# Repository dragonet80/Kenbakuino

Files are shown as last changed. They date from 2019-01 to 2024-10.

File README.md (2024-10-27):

# Kenbakuino
This is a fork from: https://github.com/funnypolynomial/Kenbakuino

This is in WIP state!

Arduino emulation of the KENBAK-1




This is an Arduino-based emulation of the 
[KENBAK-1](https://en.wikipedia.org/wiki/Kenbak-1 "Wikipedia"), considered by some to be the first "personal computer".  It was first advertised for sale in the September 1971 issue of Scientific American.

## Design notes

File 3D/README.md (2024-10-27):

DWG (AutoCAD) and STL files



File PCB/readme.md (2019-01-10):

Fitxers per a la PCB en format Autodesk Eagle

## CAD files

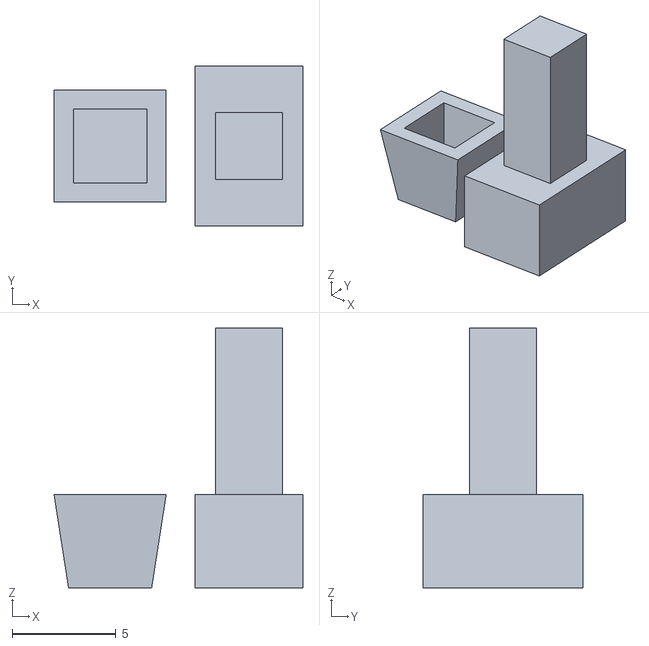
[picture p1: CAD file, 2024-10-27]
3D/Kenbak_boto3.stl
12.0 x 7.70 x 12.5

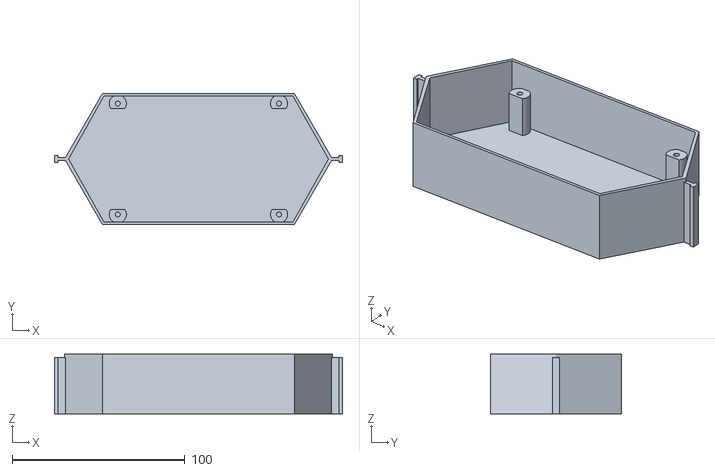
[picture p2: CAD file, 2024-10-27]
3D/Kenbak_caixa.stl
166.7 x 76.0 x 34.5

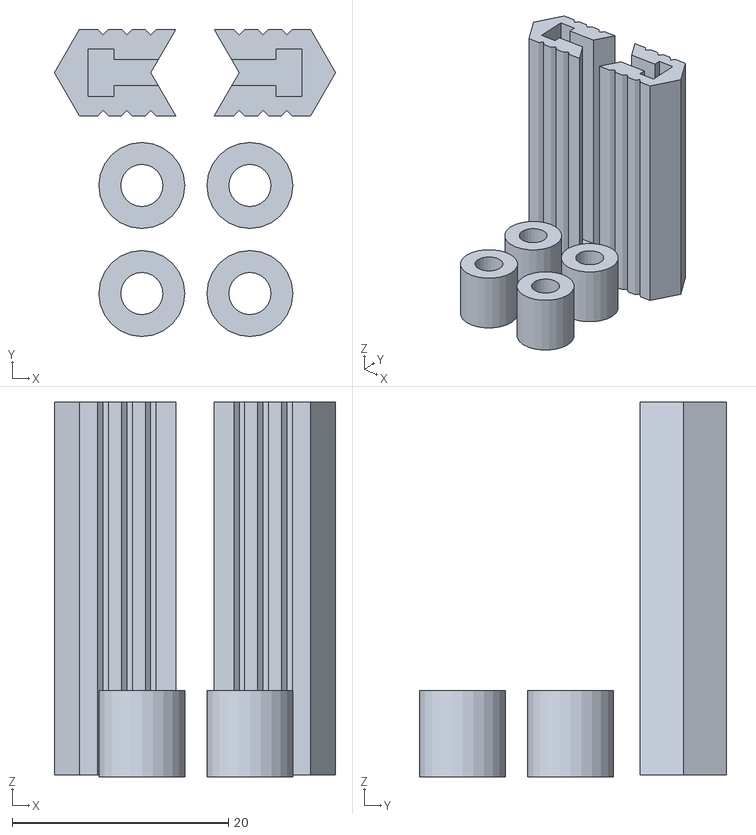
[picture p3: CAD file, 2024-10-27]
3D/Kenbak_tap.stl
26.0 x 28.4 x 34.7

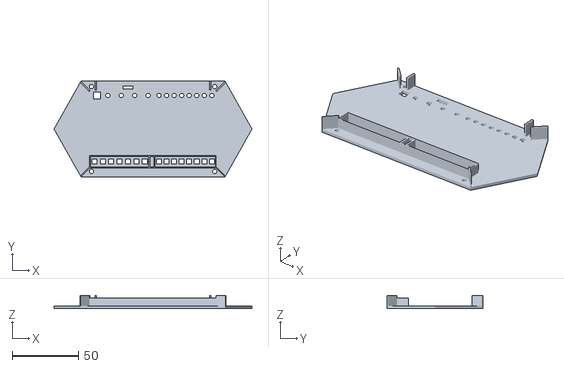
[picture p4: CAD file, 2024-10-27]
3D/Kenbak_tapa2.stl
149.9 x 72.6 x 10.00

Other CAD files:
3D/Kenbak-nanoduino_v2_005.dwg
3D/CajaKenbak3.dwg

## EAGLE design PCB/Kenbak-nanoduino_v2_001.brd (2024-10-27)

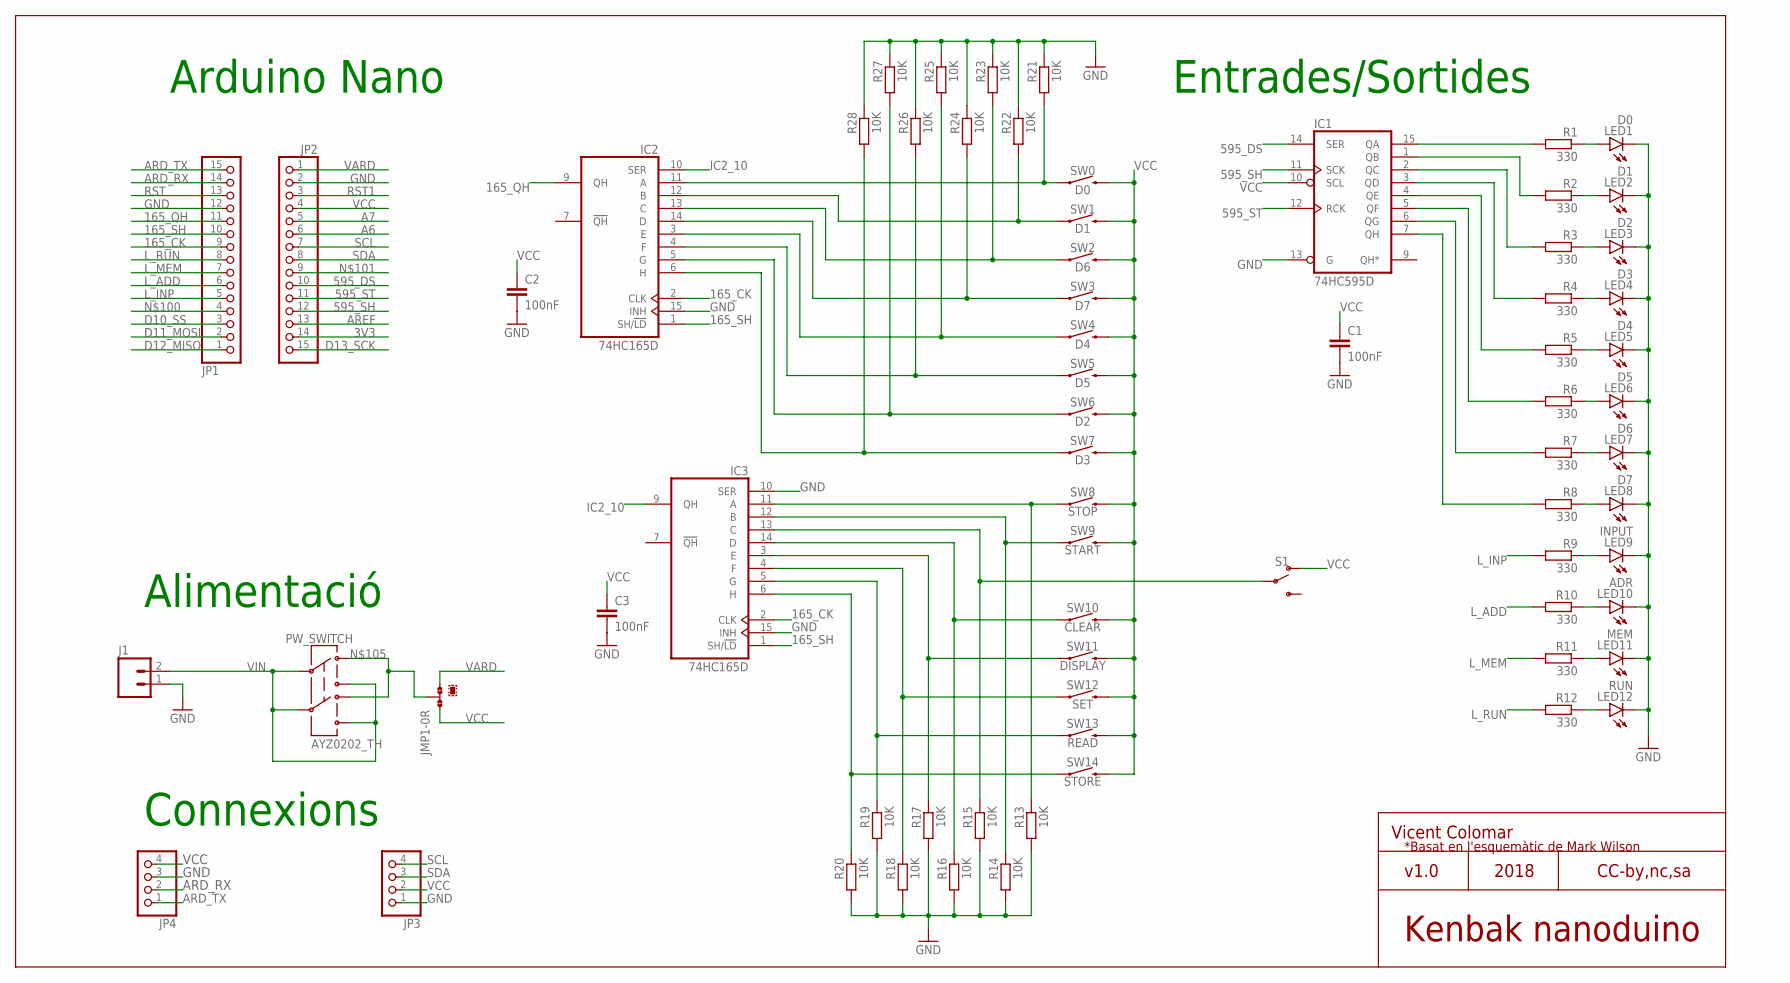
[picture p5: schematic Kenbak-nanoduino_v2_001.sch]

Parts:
C1, C2, C3: 100nF; C1206
IC1: 74HC595D; SO16
IC2, IC3: 74HC165D; SO16
J1: M02LOCK_LONGPADS; 1X02_LOCK_LONGPADS
JMP1: 0R-JUMPA; A0R-JMP
JP1, JP2: PINHD-1X15_2.54-SMD; 1X15SMD
JP3, JP4: PINHD-1X04_2.54-SMD; 1X04SMD
LED1: D0; LED3MM
LED2: D1; LED3MM
LED3: D2; LED3MM
LED4: D3; LED3MM
LED5: D4; LED3MM
LED6: D5; LED3MM
LED7: D6; LED3MM
LED8: D7; LED3MM
LED9: INPUT; LED3MM
LED10: ADR; LED3MM
LED11: MEM; LED3MM
LED12: RUN; LED3MM
PW_SWITCH: AYZ0202_TH
R1, R2, R3, R4, R5, R6, R7, R8, R9, R10, R11, R12: 330; R1206
R13, R14, R15, R16, R17, R18, R19, R20, R21, R22, R23, R24, R25, R26, R27, R28: 10K; R1206
S1: SWITCH-SPDT-PTH-11.6X4.0MM; SWITCH_SPDT_PTH_11.6X4.0MM
SW0: D0; TACTILE_SWITCH_SMD_6.0X3.5MM
SW1: D1; TACTILE_SWITCH_SMD_6.0X3.5MM
SW2: D6; TACTILE_SWITCH_SMD_6.0X3.5MM
SW3: D7; TACTILE_SWITCH_SMD_6.0X3.5MM
SW4: D4; TACTILE_SWITCH_SMD_6.0X3.5MM
SW5: D5; TACTILE_SWITCH_SMD_6.0X3.5MM
SW6: D2; TACTILE_SWITCH_SMD_6.0X3.5MM
SW7: D3; TACTILE_SWITCH_SMD_6.0X3.5MM
SW8: STOP; TACTILE_SWITCH_SMD_6.0X3.5MM
SW9: START; TACTILE_SWITCH_SMD_6.0X3.5MM
SW10: CLEAR; TACTILE_SWITCH_SMD_6.0X3.5MM
SW11: DISPLAY; TACTILE_SWITCH_SMD_6.0X3.5MM
SW12: SET; TACTILE_SWITCH_SMD_6.0X3.5MM
SW13: READ; TACTILE_SWITCH_SMD_6.0X3.5MM
SW14: STORE; TACTILE_SWITCH_SMD_6.0X3.5MM

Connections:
3V3: JP2.14
165_CK: IC2.2 (CLK), IC3.2 (CLK), JP1.9
165_QH: IC2.9 (QH), JP1.11
165_SH: IC2.1 (SH/!LD), IC3.1 (SH/!LD), JP1.10
595_DS: IC1.14 (SER), JP2.10
595_SH: IC1.11 (SCK), JP2.12
595_ST: IC1.12 (RCK), JP2.11
A6: JP2.6
A7: JP2.5
ARD_RX: JP1.14, JP4.2
ARD_TX: JP1.15, JP4.1
AREF: JP2.13
D10_SS: JP1.3
D11_MOSI: JP1.2
D12_MISO: JP1.1
D13_SCK: JP2.15
GND: C1.2, C2.2, C3.2, IC1.8 (GND), IC1.13 (G), IC2.8 (GND), IC2.15 (INH), IC3.8 (GND), IC3.10 (SER), IC3.15 (INH), J1.1, JP1.12, JP2.2, JP3.1, JP4.3, LED1.K (C), LED2.K (C), LED3.K (C), LED4.K (C), LED5.K (C), LED6.K (C), LED7.K (C), LED8.K (C), LED9.K (C), LED10.K (C), LED11.K (C), LED12.K (C), R13.2, R14.2, R15.2, R16.2, R17.2, R18.2, R19.2, R20.2, R21.1, R22.1, R23.1, R24.1, R25.1, R26.1, R27.1, R28.1
IC2_10: IC2.10 (SER), IC3.9 (QH)
L_ADD: JP1.6, R10.2
L_INP: JP1.5, R9.2
L_MEM: JP1.7, R11.2
L_RUN: JP1.8, R12.2
unnamed: LED1.A, R1.1
unnamed: LED2.A, R2.1
unnamed: LED3.A, R3.1
unnamed: LED4.A, R4.1
unnamed: LED5.A, R5.1
unnamed: LED6.A, R6.1
unnamed: LED7.A, R7.1
unnamed: LED8.A, R8.1
unnamed: LED9.A, R9.1
unnamed: LED10.A, R10.1
unnamed: LED11.A, R11.1
unnamed: LED12.A, R12.1
unnamed: IC1.15 (QA), R1.2
unnamed: IC1.1 (QB), R2.2
unnamed: IC1.2 (QC), R3.2
unnamed: IC1.3 (QD), R4.2
unnamed: IC1.4 (QE), R5.2
unnamed: IC1.5 (QF), R6.2
unnamed: IC1.6 (QG), R7.2
unnamed: IC1.7 (QH), R8.2
unnamed: IC2.11 (A), R21.2, SW0.1
unnamed: IC2.12 (B), R22.2, SW1.1
unnamed: IC2.13 (C), R23.2, SW2.1
unnamed: IC2.14 (D), R24.2, SW3.1
unnamed: IC3.13 (C), R15.1, S1.2
unnamed: IC2.3 (E), R25.2, SW4.1
unnamed: IC2.4 (F), R26.2, SW5.1
unnamed: IC2.5 (G), R27.2, SW6.1
unnamed: IC2.6 (H), R28.2, SW7.1
unnamed: IC3.11 (A), R13.1, SW8.1
unnamed: IC3.12 (B), R14.1, SW9.1
unnamed: IC3.14 (D), R16.1, SW10.1
unnamed: IC3.3 (E), R17.1, SW11.1
unnamed: IC3.4 (F), R18.1, SW12.1
unnamed: IC3.5 (G), R19.1, SW13.1
unnamed: IC3.6 (H), R20.1, SW14.1
unnamed: JMP1.2, PW_SWITCH.D1, PW_SWITCH.D2
RST: JP1.13
RST1: JP2.3
SCL: JP2.7, JP3.4
SDA: JP2.8, JP3.3
VARD: JMP1.3, JP2.1
VCC: C1.1, C2.1, C3.1, IC1.10 (SCL), IC1.16 (VCC), IC2.16 (VCC), IC3.16 (VCC), JMP1.1, JP2.4, JP3.2, JP4.4, S1.1 (O), SW0.2, SW1.2, SW2.2, SW3.2, SW4.2, SW5.2, SW6.2, SW7.2, SW8.2, SW9.2, SW10.2, SW11.2, SW12.2, SW13.2, SW14.2
VIN: J1.2, PW_SWITCH.B1, PW_SWITCH.B2, PW_SWITCH.C1, PW_SWITCH.C2

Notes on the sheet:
Alimentació
Arduino Nano
Kenbak nanoduino
v1.0
2018
CC-by,nc,sa
Vicent Colomar
Connexions
Entrades/Sortides
*Basat en l'esquemàtic de Mark Wilson

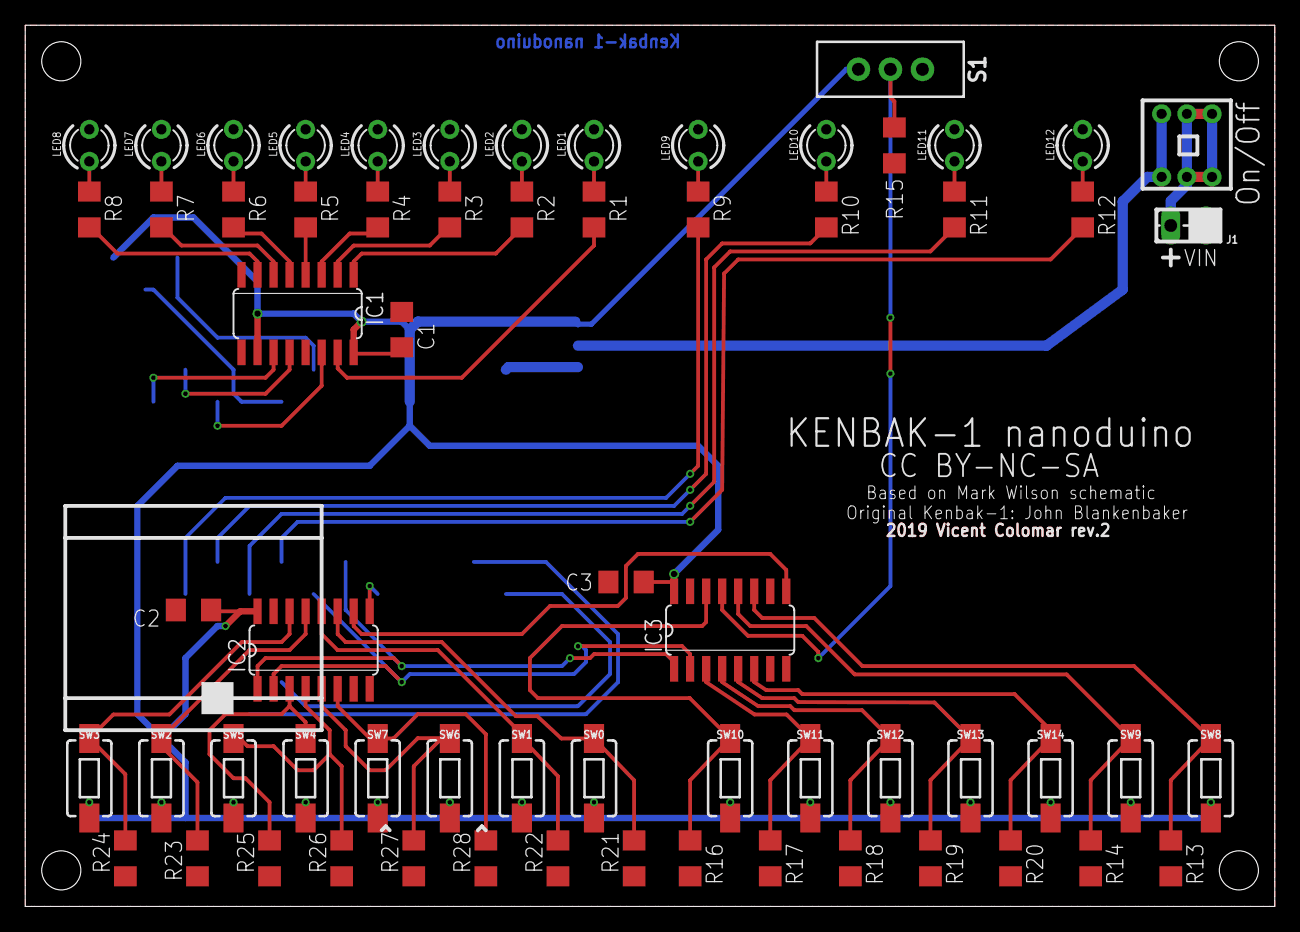
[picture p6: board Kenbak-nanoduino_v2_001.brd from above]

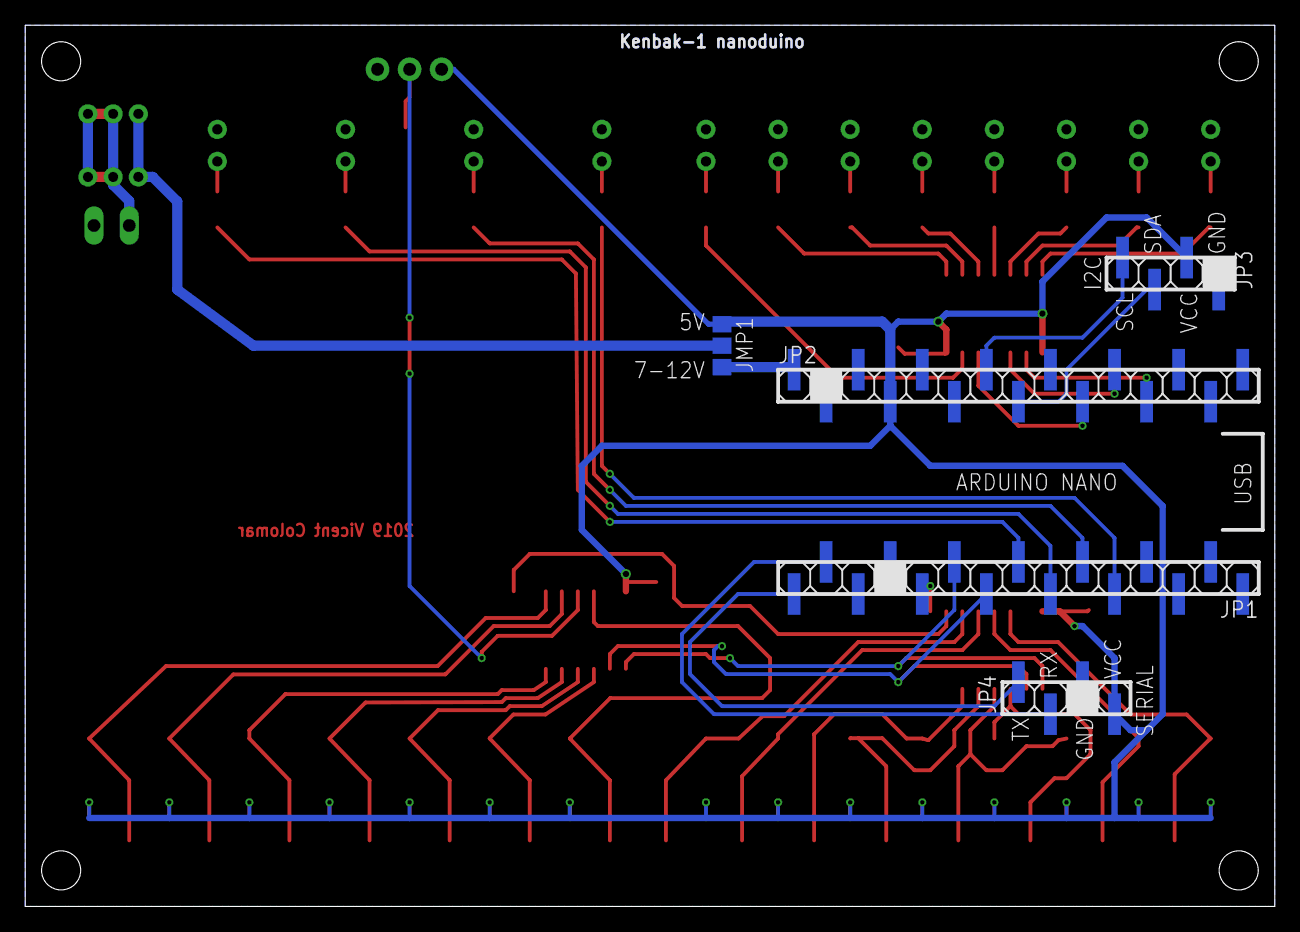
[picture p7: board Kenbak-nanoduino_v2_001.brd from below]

Board: 2 copper layers, 99.0 x 69.8 mm, 69 parts (5 on the bottom side), 56 nets.

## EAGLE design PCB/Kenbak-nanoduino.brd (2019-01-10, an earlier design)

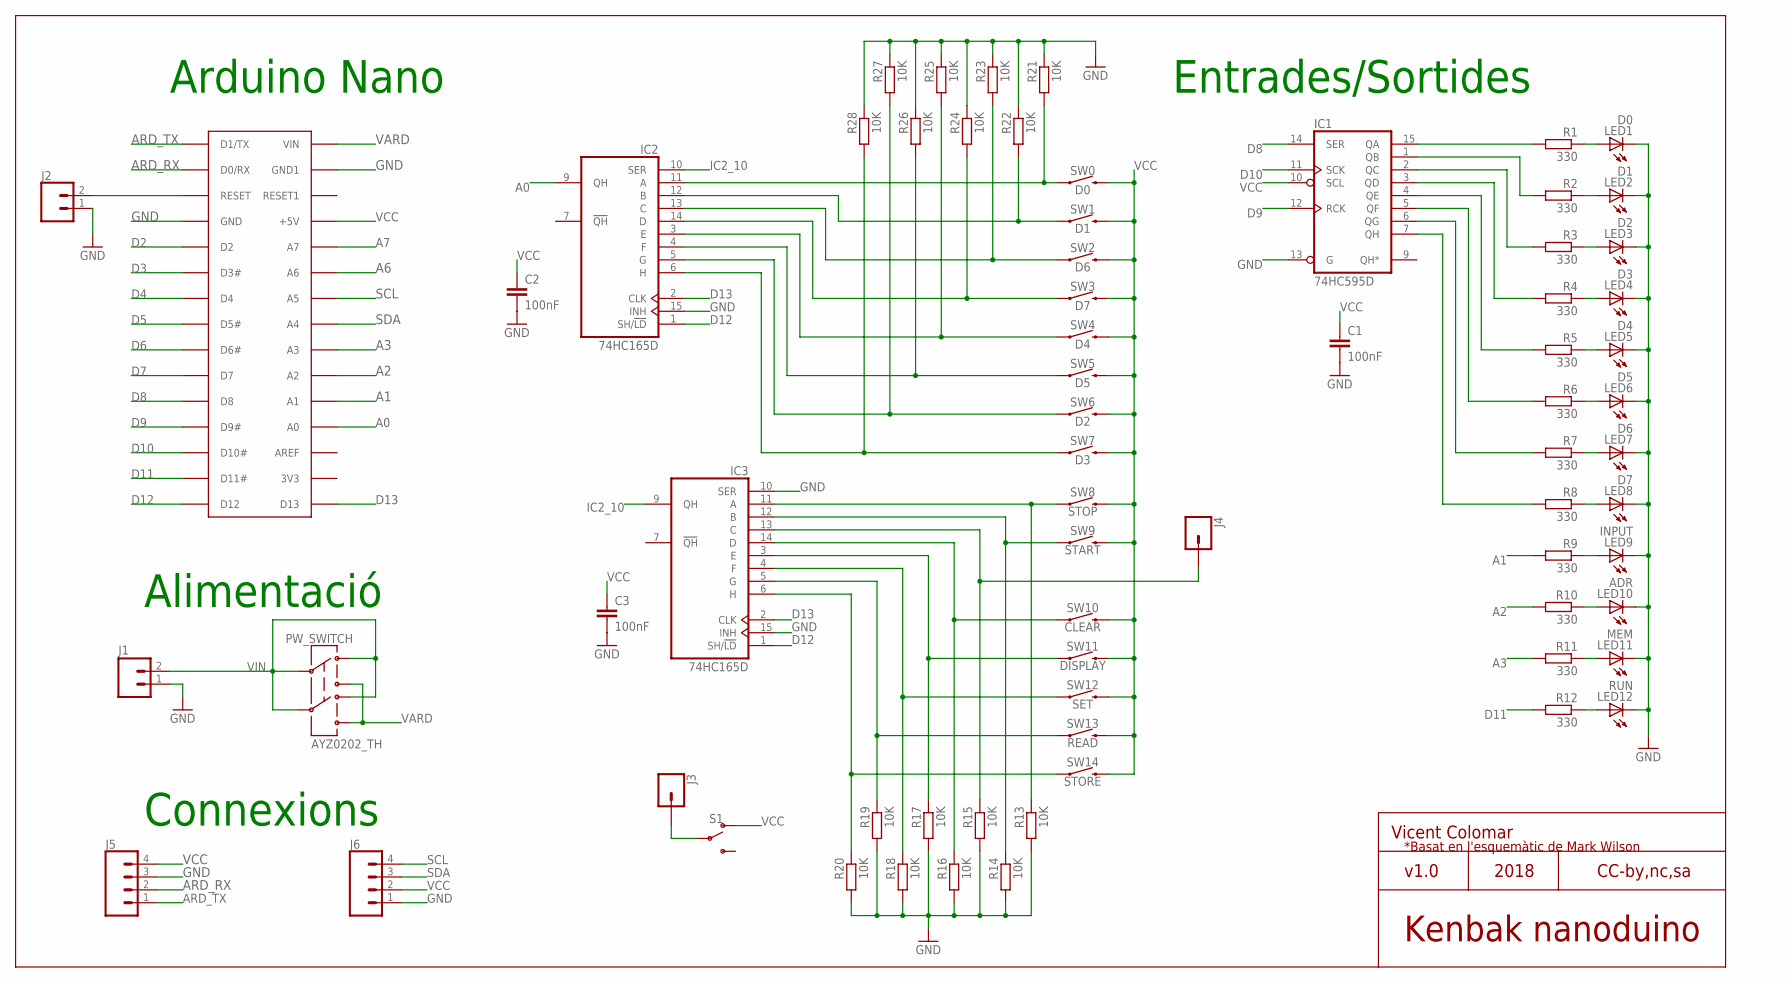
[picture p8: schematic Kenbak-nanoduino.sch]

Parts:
ARDUINO: NANO; PDIP-32NOHOLES
C1, C2, C3: 100nF; C1206
IC1: 74HC595D; SO16
IC2, IC3: 74HC165D; SO16
J1: M02LOCK_LONGPADS; 1X02_LOCK_LONGPADS
J2: CONN_02; 1X02
J3, J4: CONN_01; 1X01
J5, J6: CONN_04; 1X04
LED1: D0; LED3MM
LED2: D1; LED3MM
LED3: D2; LED3MM
LED4: D3; LED3MM
LED5: D4; LED3MM
LED6: D5; LED3MM
LED7: D6; LED3MM
LED8: D7; LED3MM
LED9: INPUT; LED3MM
LED10: ADR; LED3MM
LED11: MEM; LED3MM
LED12: RUN; LED3MM
PW_SWITCH: AYZ0202_TH
R1, R2, R3, R4, R5, R6, R7, R8, R9, R10, R11, R12: 330; R1206
R13, R14, R15, R16, R17, R18, R19, R20, R21, R22, R23, R24, R25, R26, R27, R28: 10K; R1206
S1: SWITCH-SPDT-PTH-11.6X4.0MM; SWITCH_SPDT_PTH_11.6X4.0MM
SW0: D0; TACTILE_SWITCH_PTH_6.0X3.5MM
SW1: D1; TACTILE_SWITCH_PTH_6.0X3.5MM
SW2: D6; TACTILE_SWITCH_PTH_6.0X3.5MM
SW3: D7; TACTILE_SWITCH_PTH_6.0X3.5MM
SW4: D4; TACTILE_SWITCH_PTH_6.0X3.5MM
SW5: D5; TACTILE_SWITCH_PTH_6.0X3.5MM
SW6: D2; TACTILE_SWITCH_PTH_6.0X3.5MM
SW7: D3; TACTILE_SWITCH_PTH_6.0X3.5MM
SW8: STOP; TACTILE_SWITCH_PTH_6.0X3.5MM
SW9: START; TACTILE_SWITCH_PTH_6.0X3.5MM
SW10: CLEAR; TACTILE_SWITCH_PTH_6.0X3.5MM
SW11: DISPLAY; TACTILE_SWITCH_PTH_6.0X3.5MM
SW12: SET; TACTILE_SWITCH_PTH_6.0X3.5MM
SW13: READ; TACTILE_SWITCH_PTH_6.0X3.5MM
SW14: STORE; TACTILE_SWITCH_PTH_6.0X3.5MM

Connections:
A0: ARDUINO.A0, IC2.9 (QH)
A1: ARDUINO.A1, R9.2
A2: ARDUINO.A2, R10.2
A3: ARDUINO.A3, R11.2
A6: ARDUINO.A6
A7: ARDUINO.A7
ARD_RX: ARDUINO.D0/RX, J5.2
ARD_TX: ARDUINO.D1/TX, J5.1
D2: ARDUINO.D2
D3: ARDUINO.D3 (D3#)
D4: ARDUINO.D4
D5: ARDUINO.D5 (D5#)
D6: ARDUINO.D6 (D6#)
D7: ARDUINO.D7
D8: ARDUINO.D8, IC1.14 (SER)
D9: ARDUINO.D9 (D9#), IC1.12 (RCK)
D10: ARDUINO.D10 (D10#), IC1.11 (SCK)
D11: ARDUINO.D11 (D11#), R12.2
D12: ARDUINO.D12, IC2.1 (SH/!LD), IC3.1 (SH/!LD)
D13: ARDUINO.D13, IC2.2 (CLK), IC3.2 (CLK)
GND: ARDUINO.GND, ARDUINO.GND1, C1.2, C2.2, C3.2, IC1.8 (GND), IC1.13 (G), IC2.8 (GND), IC2.15 (INH), IC3.8 (GND), IC3.10 (SER), IC3.15 (INH), J1.1, J2.1, J5.3, J6.1, LED1.K (C), LED2.K (C), LED3.K (C), LED4.K (C), LED5.K (C), LED6.K (C), LED7.K (C), LED8.K (C), LED9.K (C), LED10.K (C), LED11.K (C), LED12.K (C), R13.2, R14.2, R15.2, R16.2, R17.2, R18.2, R19.2, R20.2, R21.1, R22.1, R23.1, R24.1, R25.1, R26.1, R27.1, R28.1
IC2_10: IC2.10 (SER), IC3.9 (QH)
unnamed: LED1.A, R1.1
unnamed: LED2.A, R2.1
unnamed: LED3.A, R3.1
unnamed: LED4.A, R4.1
unnamed: LED5.A, R5.1
unnamed: LED6.A, R6.1
unnamed: LED7.A, R7.1
unnamed: LED8.A, R8.1
unnamed: LED9.A, R9.1
unnamed: LED10.A, R10.1
unnamed: LED11.A, R11.1
unnamed: LED12.A, R12.1
unnamed: IC1.15 (QA), R1.2
unnamed: IC1.1 (QB), R2.2
unnamed: IC1.2 (QC), R3.2
unnamed: IC1.3 (QD), R4.2
unnamed: IC1.4 (QE), R5.2
unnamed: IC1.5 (QF), R6.2
unnamed: IC1.6 (QG), R7.2
unnamed: IC1.7 (QH), R8.2
unnamed: IC2.11 (A), R21.2, SW0.P$1 (1)
unnamed: IC2.12 (B), R22.2, SW1.P$1 (1)
unnamed: IC2.13 (C), R23.2, SW2.P$1 (1)
unnamed: IC2.14 (D), R24.2, SW3.P$1 (1)
unnamed: J3.1, S1.2
unnamed: IC2.3 (E), R25.2, SW4.P$1 (1)
unnamed: IC2.4 (F), R26.2, SW5.P$1 (1)
unnamed: IC2.5 (G), R27.2, SW6.P$1 (1)
unnamed: IC2.6 (H), R28.2, SW7.P$1 (1)
unnamed: IC3.11 (A), R13.1, SW8.P$1 (1)
unnamed: IC3.12 (B), R14.1, SW9.P$1 (1)
unnamed: IC3.13 (C), J4.1, R15.1
unnamed: IC3.14 (D), R16.1, SW10.P$1 (1)
unnamed: IC3.3 (E), R17.1, SW11.P$1 (1)
unnamed: IC3.4 (F), R18.1, SW12.P$1 (1)
unnamed: IC3.5 (G), R19.1, SW13.P$1 (1)
unnamed: IC3.6 (H), R20.1, SW14.P$1 (1)
unnamed: ARDUINO.RESET, J2.2
SCL: ARDUINO.A5, J6.4
SDA: ARDUINO.A4, J6.3
VARD: ARDUINO.VIN, PW_SWITCH.B1, PW_SWITCH.B2
VCC: ARDUINO.+5V, C1.1, C2.1, C3.1, IC1.10 (SCL), IC1.16 (VCC), IC2.16 (VCC), IC3.16 (VCC), J5.4, J6.2, S1.1 (O), SW0.P$2 (2), SW1.P$2 (2), SW2.P$2 (2), SW3.P$2 (2), SW4.P$2 (2), SW5.P$2 (2), SW6.P$2 (2), SW7.P$2 (2), SW8.P$2 (2), SW9.P$2 (2), SW10.P$2 (2), SW11.P$2 (2), SW12.P$2 (2), SW13.P$2 (2), SW14.P$2 (2)
VIN: J1.2, PW_SWITCH.C1, PW_SWITCH.C2, PW_SWITCH.D1, PW_SWITCH.D2

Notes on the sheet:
Alimentació
Arduino Nano
Kenbak nanoduino
v1.0
2018
CC-by,nc,sa
Vicent Colomar
Connexions
Entrades/Sortides
*Basat en l'esquemàtic de Mark Wilson

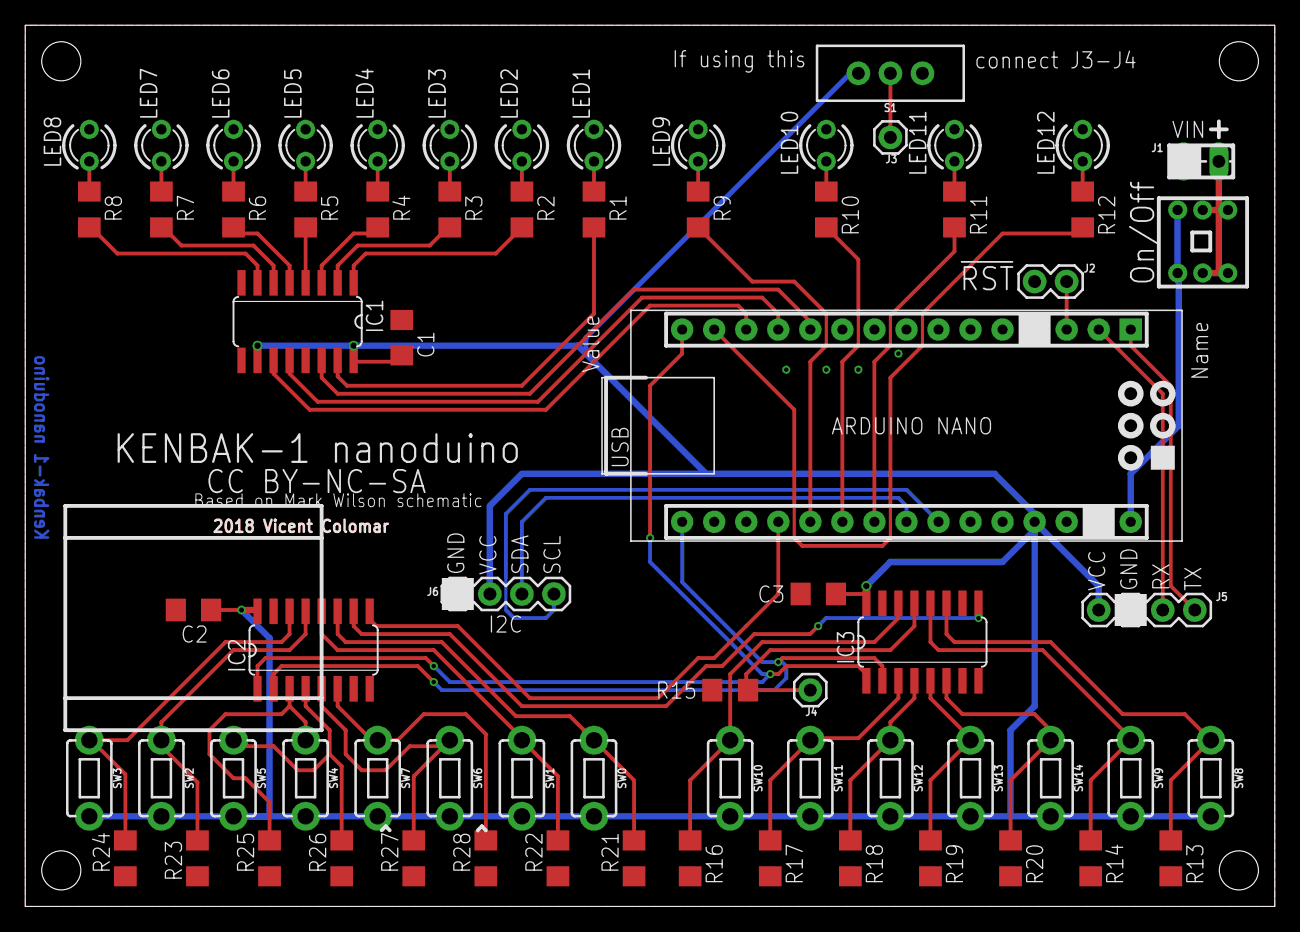
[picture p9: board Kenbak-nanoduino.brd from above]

Board: 2 copper layers, 99.0 x 69.8 mm, 70 parts (0 on the bottom side), 57 nets.

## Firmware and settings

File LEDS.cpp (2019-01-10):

#include <Arduino.h>
#include "PINS.h"
#include "MCP.h"
#include "LEDS.h"

void LEDs::Init()
{
  // the 595 controls the 8 data LEDs
  pinMode(PIN_LEDS_DS, OUTPUT);
  pinMode(PIN_LEDS_ST, OUTPUT);
  pinMode(PIN_LEDS_SH, OUTPUT);
  ShiftOut(0x00);
  m_LastData = 0;

  // the 4 control LEDs have a direct link
  for (int Pin = MCP::eInput; Pin <= MCP::eRun; Pin++)
  {
    pinMode(m_pDirectControlPins[Pin], OUTPUT);
    digitalWrite(m_pDirectControlPins[Pin], LOW);
  }
  m_LastControl = 0;
}

void LEDs::ShiftOut(byte LEDs)
{
  digitalWrite(PIN_LEDS_ST, LOW);
  // shift out the bits:
  //shiftOut(PIN_LEDS_DS, PIN_LEDS_SH, LSBFIRST, LEDs); /* Original from Mark Wilson. gives data leds inverted positions to me */
  shiftOut(PIN_LEDS_DS, PIN_LEDS_SH, MSBFIRST, LEDs);
  //take the latch pin high so the LEDs will light up:
  digitalWrite(PIN_LEDS_ST, HIGH);
}

void LEDs::Display(byte Data, byte Control)
{
  // update the data and control LEDs
  if (Data != m_LastData)
  {
    ShiftOut(Data);
    m_LastData = Data;
  }
  
  if (Control != m_LastControl)
  {
    for (int Pin = MCP::eInput; Pin < MCP::eRun; Pin++)
    {
      digitalWrite(m_pDirectControlPins[Pin], bitRead(Control, Pin)?HIGH:LOW);
    }
    
    if (bitRead(Control, MCP::eRun))
    {
      // the Run LED can do PWM, use the upper 4 bits; 0000 = max brightness (255) 1111 = min (16)
      analogWrite(m_pDirectControlPins[MCP::eRun], 0xFF - (Control & 0xF0));
    }
    else
    {
      digitalWrite(m_pDirectControlPins[MCP::eRun], LOW);
    }
    m_LastControl = Control;
  }
}

// pin mapping in the same order as MCP::tMode
byte LEDs::m_pDirectControlPins[] =
{
  PIN_LED_INP,
  PIN_LED_ADDR,
  PIN_LED_MEM,
  PIN_LED_RUN_PWM
};

LEDs leds = LEDs();

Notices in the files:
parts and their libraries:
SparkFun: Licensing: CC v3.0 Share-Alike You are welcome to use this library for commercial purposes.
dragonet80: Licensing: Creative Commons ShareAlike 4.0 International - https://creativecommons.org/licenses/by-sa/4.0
